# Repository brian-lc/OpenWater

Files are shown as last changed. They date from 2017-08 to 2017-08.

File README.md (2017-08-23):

# OpenWater
This is an open source hardware project. It is published under the CERN OpenHardware License. https://www.ohwr.org/documents/294

#Note!
This is very much a work in progress. All designs are subject to change.

## Goal
To create and share an open source water monitoring system that was capable of measuring water temperature, pH, and ORP. 

This repo contains all the hardware, software, 3D models, and instructions on how to create your own version. 

## Bill of Materials (all versions)
https://docs.google.com/spreadsheets/d/1hH_PX7qE9Eqqa5zU-xhwlhM-gbqpwk3e61Kn0q8U03g/edit?usp=sharing

# History

## V3 - Pelican case - WIP
This version rethinks the whole approach and tries to again use a simple enclosure to house the electronics and keep things water-tight. Forget submerged housings and dealing with buoyancy. This will use some foam and the Pelican case to keep the device on top of the water. It'll be bigger but it will also allow the placement of a solar panel on top. 

## V2 - Inflatable 
This design throws away the idea that the enclosure needs to be rigid. Using a flexible tubing (originally designed for industrial processing) I created an enclosure that could be inflated/deflated to adjust for buoyancy. What I learned was that 1) buoyancy is hard to get right when it's a DIY project. Even the slightest off center mass (like a cable on one side) could cause the whole setup to list. Also, USB cables rust. Also also, making something water tight is hard. The first time I floated this in an over-night test the whole inside filled with water because the air pressure stem didn't have enough back-pressure to keep the water out. Luckily none of the electronics were harmed. 

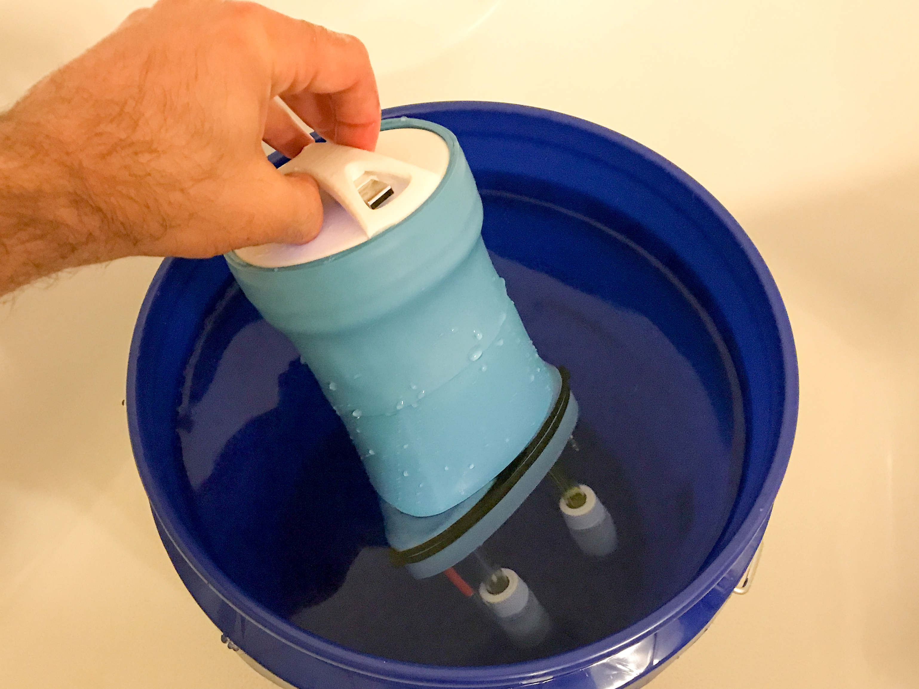
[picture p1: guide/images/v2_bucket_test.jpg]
V2 - Inflatable Prototype V2 - Inflatable Prototype bucket test


## V1 - Blender Bottle
My first attempt at a cheap ($11 USD) enclosure using an off-the-shelf blender bottle. With just a few components this design came together well but it proved to be too difficult to service the battery. Also, the cabling situation was a nightmare. The probes each come with about 5 feet of coax. Dealing with it is a real pain. 

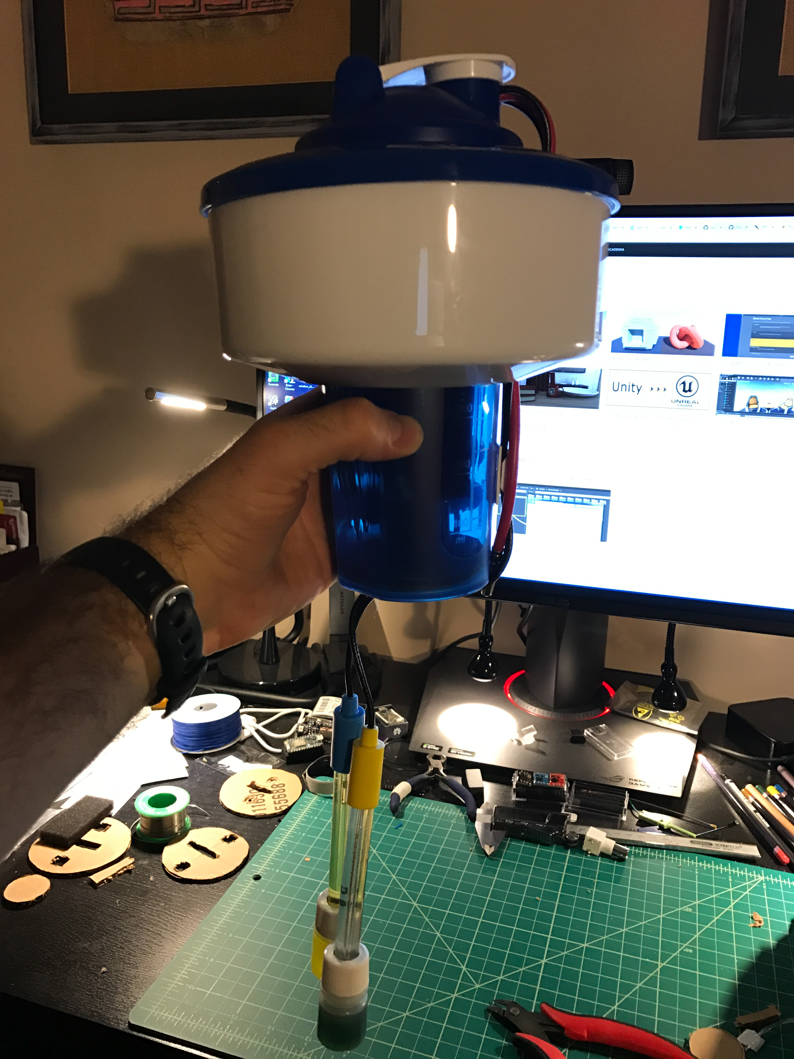
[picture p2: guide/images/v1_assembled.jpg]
V1 - BlenderBottle V1 - BlenderBottle assembled


### Resources and other projects
https://www.voltaicsystems.com/blog/building-solar-powered-cloud-connected-devices/

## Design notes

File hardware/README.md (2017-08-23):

## Hardware
Here are the eagle source files for the OpenWater PCB. It's a very straightforward design. There are no parts on the PCB itself except for a few pull up resistors (which are not technically needed if you rely on the ones from the internal temp/humidity board by Sparkfun). Also, it has two mount holes placed for easy fastening to an enclosure. See 3D files for details.

The gerbers included here are for version 2 since I used Eagle for V2. For the first version I used Upverter. You can find that project here: https://upverter.com/breakpointer/075962a4a041eaf9/OpenWater_v1/

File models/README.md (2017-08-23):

## 3D models
Your milage my vary on this. I went through two (and now soon three) different iterations on the design. These are here to look at really. If you want to print them or view them follow the following links:

V2
https://www.sculpteo.com/en/print/openwater_topcap_v11/xwHAnrdN

https://www.sculpteo.com/en/print/openwater_bottomcap_v1/HKhis2ST

V1
https://www.sculpteo.com/en/print/ow_top_trim/Enp2pLMD

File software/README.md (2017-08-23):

## Software instructions
Copy this code to a new project in the Particle.io IDE and flash it to your device.

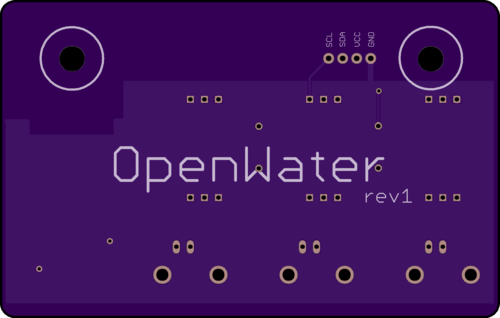
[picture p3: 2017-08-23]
hardware/OWBoardRev1Bottom.png

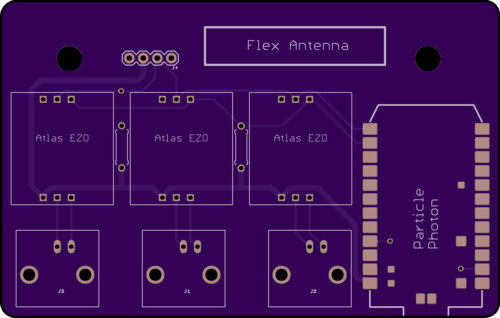
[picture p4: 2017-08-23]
hardware/OWBoardRev1Top.png

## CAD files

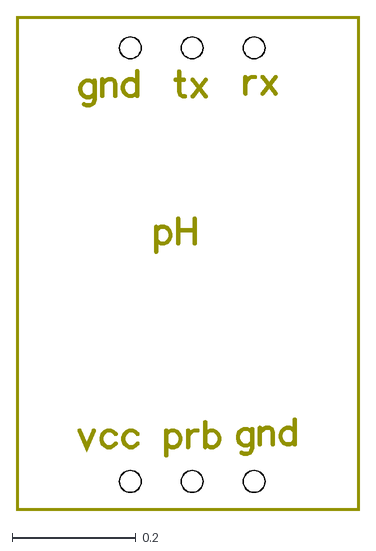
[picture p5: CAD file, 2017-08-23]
hardware/ph-footprint/ph-layout.dxf
0.555 x 0.798

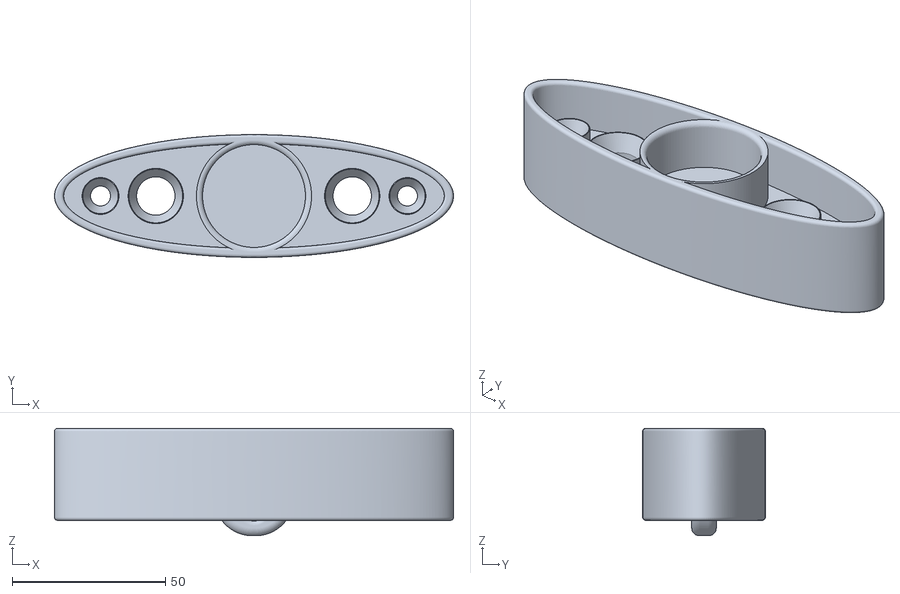
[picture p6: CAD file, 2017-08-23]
models/v2/OpenWater_BottomCap_v1.stl
130.0 x 40.0 x 35.0

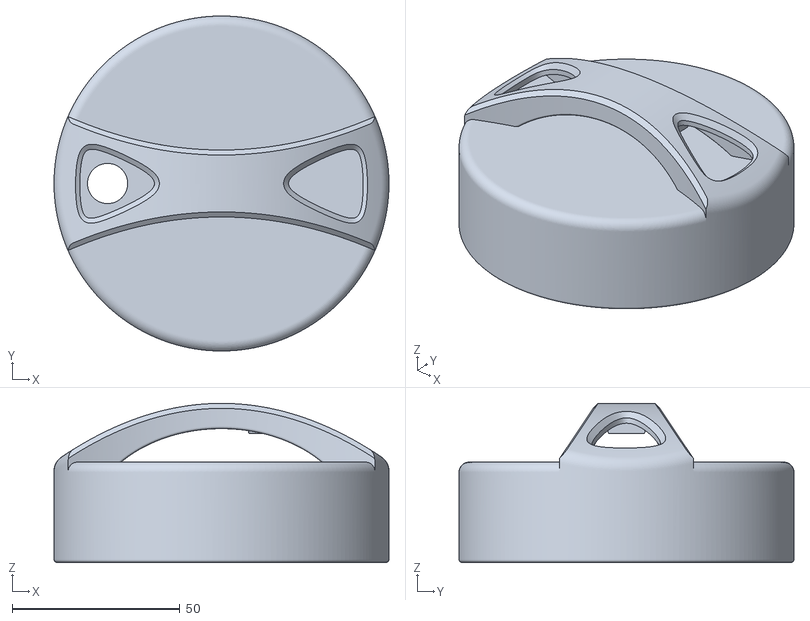
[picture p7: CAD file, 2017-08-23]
models/v2/OpenWater_TopCap_v1.stl
100.0 x 100.0 x 47.5

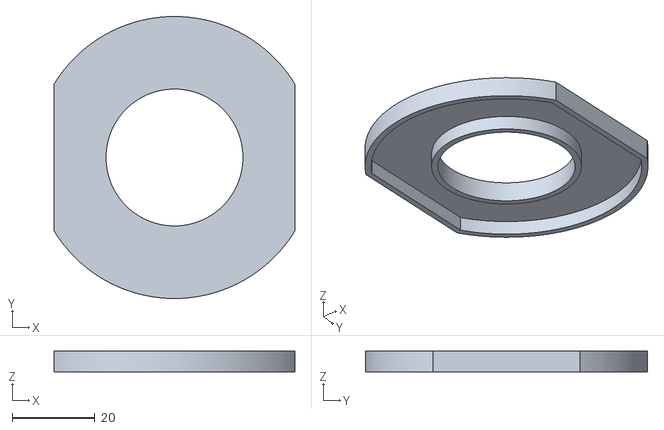
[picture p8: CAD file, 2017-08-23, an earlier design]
models/v1/OW_bottom.stl
58.0 x 68.0 x 5.00

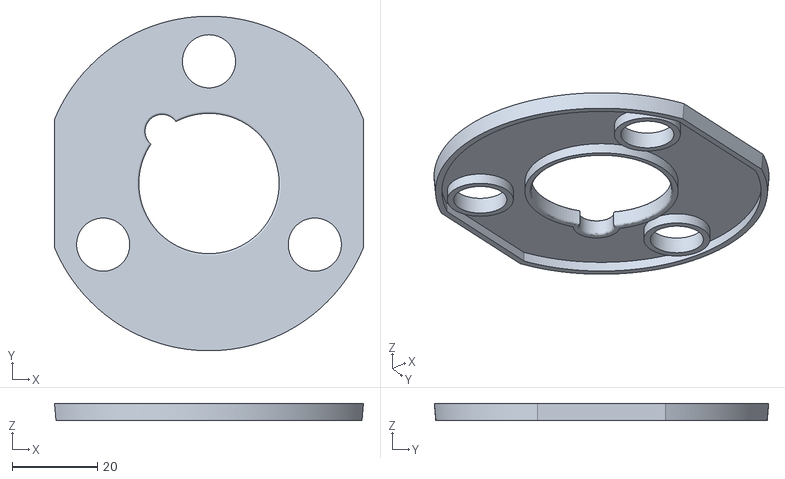
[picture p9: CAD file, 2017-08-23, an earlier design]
models/v1/OW_top_trim.stl
72.7 x 78.7 x 4.00

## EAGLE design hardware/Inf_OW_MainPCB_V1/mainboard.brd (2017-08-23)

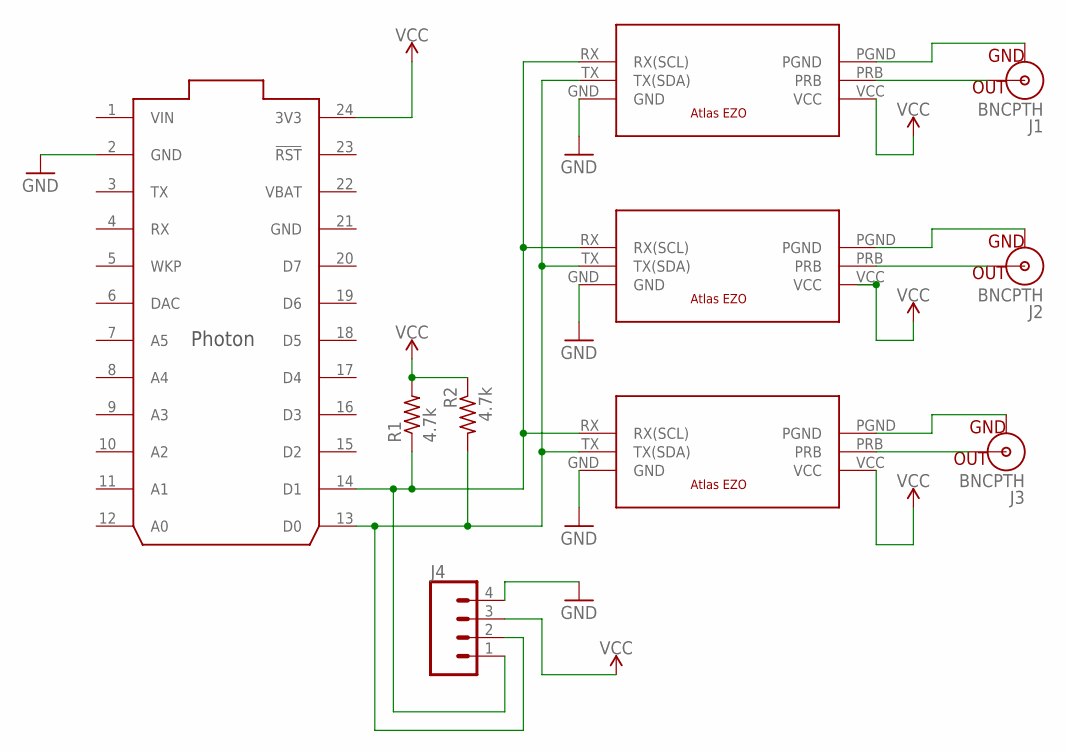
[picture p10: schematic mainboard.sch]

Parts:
J1, J2, J3: BNCPTH; BNC
J4: CONN_04; 1X04
R1, R2: 4.7k; 0207/7
U$1: PHOTON_SMD
U$2, U$3, U$4: ATLSCI_EZO; ATLAS_SCI_EZO

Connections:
GND: J4.4, U$1.2 (GND), U$1.21 (GND), U$2.GND, U$3.GND, U$4.GND
unnamed: J4.1, R1.1, U$1.14 (D1), U$2.RX (RX(SCL)), U$3.RX (RX(SCL)), U$4.RX (RX(SCL))
unnamed: J4.2, R2.2, U$1.13 (D0), U$2.TX (TX(SDA)), U$3.TX (TX(SDA)), U$4.TX (TX(SDA))
unnamed: J2.S (OUT), U$3.PRB
unnamed: J2.GND, U$3.PGND
unnamed: J1.S (OUT), U$2.PRB
unnamed: J1.GND, U$2.PGND
unnamed: J3.S (OUT), U$4.PRB
unnamed: J3.GND, U$4.PGND
VBAT: U$1.22 (VBAT)
VCC: J4.3, R1.2, R2.1, U$1.24 (3V3), U$2.VCC, U$3.VCC, U$4.VCC
VIN: U$1.1 (VIN)

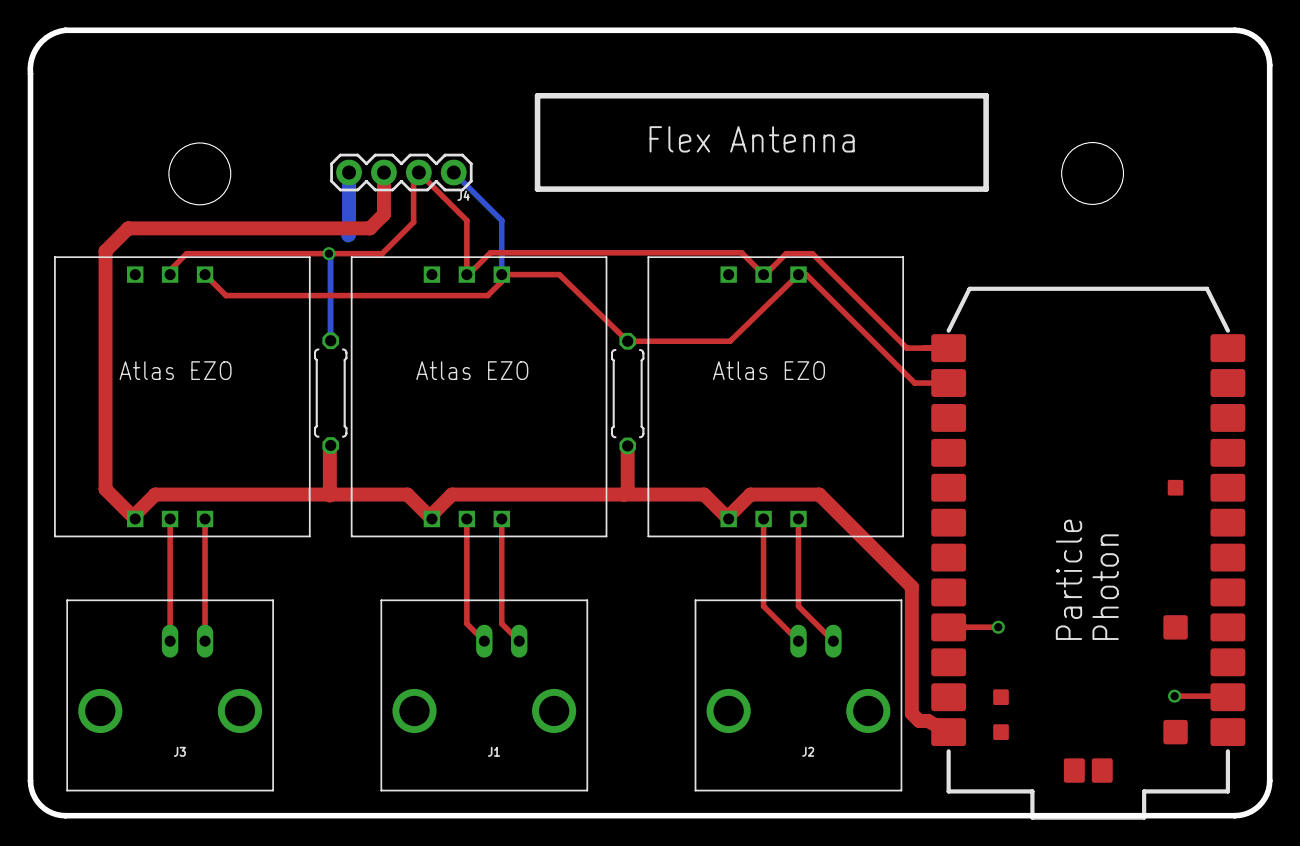
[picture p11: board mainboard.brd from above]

Board: 2 copper layers, 90.2 x 57.1 mm, 10 parts (0 on the bottom side), 10 nets.

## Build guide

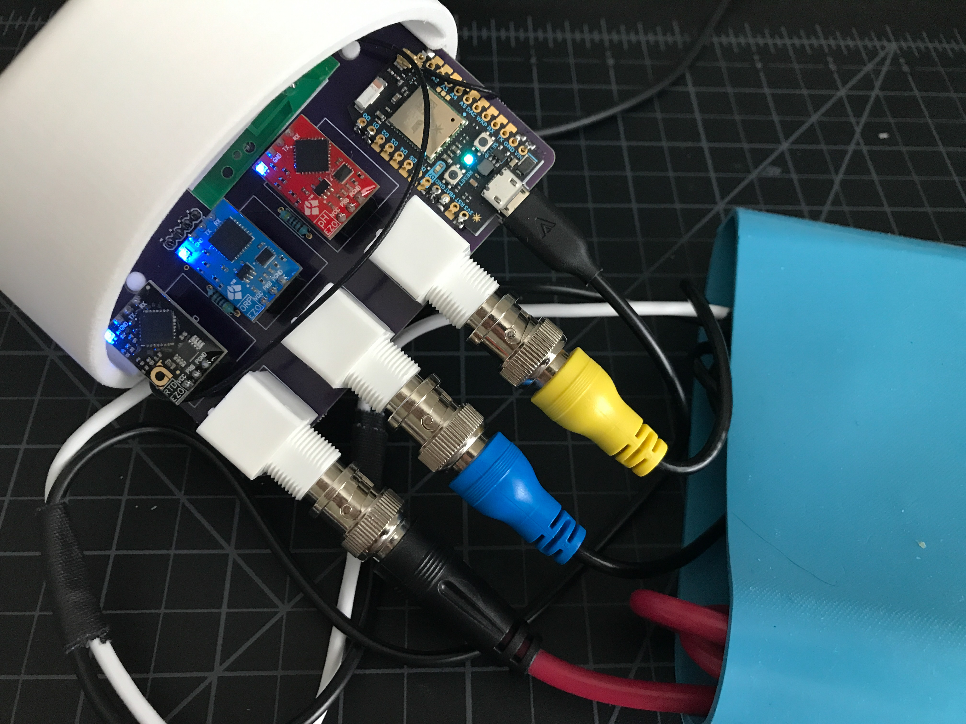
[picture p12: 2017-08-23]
guide/images/v2_pcb_mounted.jpg

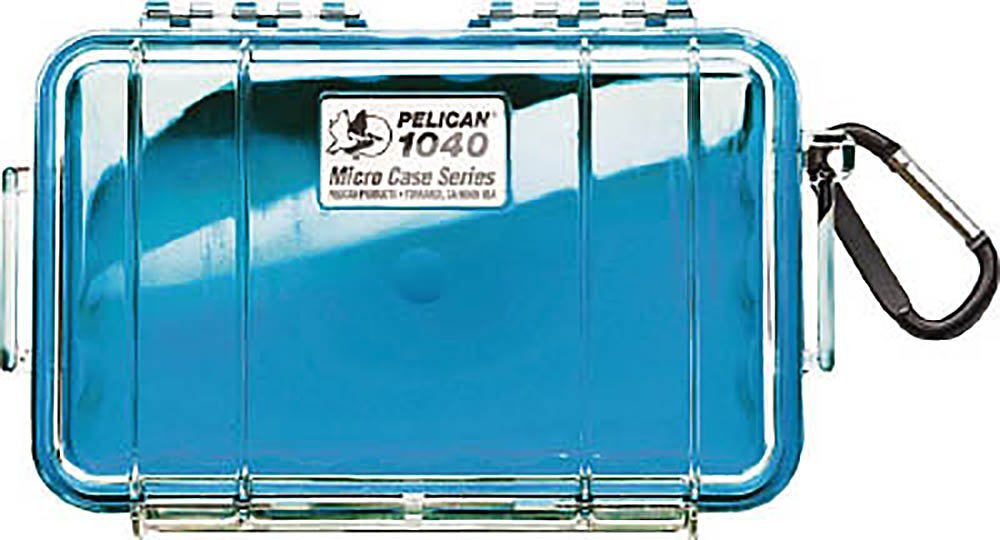
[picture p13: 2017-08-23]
guide/images/pelican_case.jpg

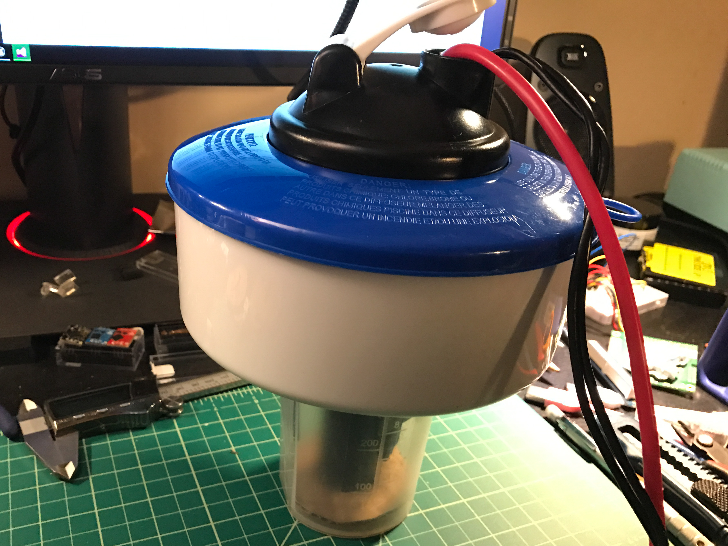
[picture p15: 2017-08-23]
guide/images/v1_rough_assemble.jpg

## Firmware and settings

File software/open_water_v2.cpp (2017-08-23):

STARTUP(WiFi.selectAntenna(ANT_EXTERNAL));

/* EZO Circuit Serial Default
 9600 bps
 8 data bits
 1 stop bit
 no parity
 no flow control 
*/

// EZO LED notes
// If LED has not been disabled the comms mode is reported as:
// LED is solid Green --> UART mode
// LED is solid Blue ---> I2C mode


int incomingByte = 0;

// For Atlas EZO comms
int orpAddr = 0x62; // ORP EZO I2C default address
int phAddr = 0x63; // PH EZO I2C default address
int tempAddr = 0x66; // Temp EZO I2C default address
int cmdDelay = 1100;  // docs say wait 1 second (or 600ms for some) after read command. Giving a 10% buffer.

// For Sparkfun Si7021 board comms
int tmpHumAddr = 0x40; //Sparkfun Si7021 I2C default address
float reading = 0.0;
int mCode = 0;

String cmdEvent = "CMD_RESP";
String dbgEvent = "DEBUG";

// Lb_ for librato
String tempEvent = "Lib_TEMP";
String phEvent = "Lib_PH";
String orpEvent = "Lib_ORP";

// Internal temp/hum measurments
String iTempEvent = "Lib_ITEMP";
String iHumEvent = "Lib_IHUM";

// Sleep flags
// EZO low power sleep
bool ezoSleep = true;

void setup() {

  // Setting up Serial to talk to the local EZO chip
  //Serial1.begin(9600, SERIAL_8N1);
  
  // Setting I2C (default 100kHz) to talk to remote EZO chips
  Wire.begin();

  // delay waiting for EZO boot
  delay(5000);
  
  // Factory reset (if needed)
  //serialCommand("Factory");
  //wireCommand(orpAddr, "Factory");
  
  // Put a device back in UART mode
  //wireCommand(tempAddr, "Baud,9600");
  //delay(300);
  //wireReadPublish("BaudCMD", tempAddr);
  
  // --Only for the EZO temp module--
  // Turn off continuous mode where
  // the ezo circuit sends readings non-stop
  // [note: LED blinks green each time a reading is sent]
  wireCommand(tempAddr, "C,0");
  wireReadPublish(cmdEvent, tempAddr);
  delay(cmdDelay);
}

void loop() {
  // ---- probe readings -----
  //Reading Temperature via I2C
  managedEZOReading(tempEvent, tempAddr);
 
  // Reading ORP via I2C
  managedEZOReading(orpEvent, orpAddr);

  // Reading pH via I2C
  managedEZOReading(phEvent, phAddr);

  // ---- internal sensor readings -----
  // Slightly different dance for the Si7021 data
  // Reading iternal chassis temp
  mCode = wireTakeMeasure(tmpHumAddr, 0xE3); //Command for Temp 
  reading = (175.25*mCode/65536)-46.85;
  ppub(iTempEvent, String::format("%.3f", reading));
  
  // Reading internal chassis humidity
  mCode = wireTakeMeasure(tmpHumAddr, 0xE5); //Command for Relative Humidity
  reading = (125.0*mCode/65536)-6;
  ppub(iHumEvent, String::format("%.3f", reading));
  
  // --- sleeping ------
  //System.sleep(SLEEP_MODE_DEEP, 300); //Sleep for 5min
  delay(6000); //chill for a min
}

// Manages the EZO circuit lifecyle: wake, read, sleep, publish
// Takes the name of event to publish (string) and device addr I2C (int)
void managedEZOReading(String eventName, int ezoAddr) {
  if (ezoSleep) {
    wakeFromSleep(ezoAddr);
  }
  
  wireCommand(ezoAddr, "R");
  delay(cmdDelay);
  wireReadPublish(eventName, ezoAddr);
  
  if (ezoSleep){
    putToSleep(ezoAddr);
  }
}

void putToSleep(int addr){
  wireCommand(addr, "Sleep");
}

void wakeFromSleep(int addr){
  // Any command will wake the device
  wireCommand(addr, "R");
  delay(cmdDelay);
}

// Reads the wire while data is available. Extracts the reading
// and formats it into a string as the return value.
String wireGetFormattedReading(int addr){
  char respBuffer[32]; // Allocated response buffer 
  int rIdx = 0;
  double reading = 0.0;
  Wire.requestFrom(addr, 8); //I2C reading is "no longer than 8 bytes"
  
  while(Wire.available()) {
    respBuffer[rIdx] = Wire.read();
    rIdx++;
  }
  if(rIdx > 0){
    respBuffer[rIdx] = '\0'; // Terminate the buffer with null char
    reading = getDouble(respBuffer); // Extract double from char buffer
    return String::format("%.3f", reading); //Format reading as string
  }
  else {
    return "???";
  }
}

// Shorthand method to read/publish
void wireReadPublish(String eventName, int addr) {
  String reading = wireGetFormattedReading(addr);
  ppub(eventName, reading);
}

// Added specifically to read the Sparkfun sensor from I2C
// Was being lazy so I lifted it from 
// https://raw.githubusercontent.com/sparkfun/Si7021_Breakout/master/Libraries/Arduino/Si7021/src/SparkFun_Si7021_Breakout_Library.cpp
// And made some slight modifications...
int wireTakeMeasure(int addr, int command){
    
    int nBytes = 3; // fresh readings are 3 bytes long
    Wire.requestFrom(addr, nBytes);
    Wire.beginTransmission(addr);
    Wire.write(command);
    Wire.endTransmission();
    // When not using clock stretching (*_NOHOLD commands) delay here
    // is needed to wait for the measurement.
    // According to datasheet the max. conversion time is ~22ms
    delay(100);
    Wire.requestFrom(addr, nBytes);
        //Wait for data
    int counter = 0;
    while (Wire.available() < nBytes){
      delay(1);
      counter ++;
      if (counter >100){
        // Timeout: Sensor did not return any data
        return 100;
      }
    }

    unsigned int msb = Wire.read();
    unsigned int lsb = Wire.read();
    // Clear the last to bits of LSB to 00.
    // According to datasheet LSB of RH is always xxxxxx10
    lsb &= 0xFC;
    int mesurment = msb << 8 | lsb;
    
    return mesurment;
}


// Optionally used during debugging/prototyping
// The EZO sensors can do serial from their TX RX pins
// This function reads from serial1 on the photon.
// NOTE: Serial1 must be initialied in setup()
void serialReadPublish(String dataName){
  char respBuffer[32]; // Allocated response buffer 
  int rIdx = 0;
  while(Serial1.available() < 0){
    // After issuing Command, EZO circuit takes 1 second to respond
    delay(10);
  }
  while(Serial1.available() > 0){
    incomingByte = Serial1.read();   
    respBuffer[rIdx] = (char) incomingByte;
    rIdx++;
  }
  if(rIdx > 0){
    respBuffer[rIdx] = '-';
    // Transmit buffer
    ppub(dataName, String(respBuffer));
  }
}

// serialCommand - Serial1Print a command string
void serialCommand(String cmd){
  //dbug("Serial<" + cmd + ">");
  Serial1.print(cmd + "\r"); // Serial commands must terminate with CR char
}

// wireCommand - I2C send command to device
void wireCommand(int addr, String cmd){
  //dbug("Wire<" + String(addr) + ":" + cmd + ">");
  Wire.beginTransmission(addr);
  Wire.write(cmd + "\0"); // I2C to EZO must terminate with the NULL char (ASCII 0)
  Wire.endTransmission();
}

void dbug(String msg){
  ppub(dbgEvent, "DEBUG:" + msg);
}

// ppub - ParticlePublish
void ppub(String dataName, String dataVal){
  Particle.publish(dataName, dataVal, 60, PRIVATE);
}

// From http://stackoverflow.com/questions/13698449/extract-double-from-a-string-in-c
double getDouble(const char *str)
{
    /* First skip non-digit characters */
    /* Special case to handle negative numbers and the `+` sign */
    while (*str && !(isdigit(*str) || ((*str == '-' || *str == '+') && isdigit(*(str + 1)))))
        str++;

    /* The parse to a double */
    return strtod(str, NULL);
}

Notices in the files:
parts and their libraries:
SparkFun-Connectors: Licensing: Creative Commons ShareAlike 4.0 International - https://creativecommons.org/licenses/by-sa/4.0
